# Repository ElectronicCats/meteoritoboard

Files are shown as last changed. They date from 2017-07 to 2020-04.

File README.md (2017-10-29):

# Meteorito Board

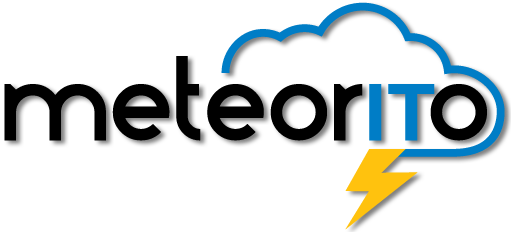
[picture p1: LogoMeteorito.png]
meteorito2


Kit de estación meteorologica para "Curso de estación y fenómenos meteorológicos" que funciona con La Red Meteorológica Ambiental([RedMet](http://redmet.org/)) promueve la difusión y concientización del cambio climático global. 

Manual, guía de arranque, curso completo y más información en [Pagina Oficial](http://meteorito.mx/index.html)

Electronic Cats invests time and resources providing this open source design, please support Electronic Cats and open-source hardware by purchasing products from Electronic Cats!

Designed by Electronic Cats.

Firmware released under an GNU AGPL v3.0 license. See the LICENSE file for more information.

Hardware released under an CERN Open Hardware Licence v1.2. See the LICENSE_HARDWARE file for more information.

Electronic Cats is a registered trademark, please do not use if you sell these PCBs.

22 July 2017

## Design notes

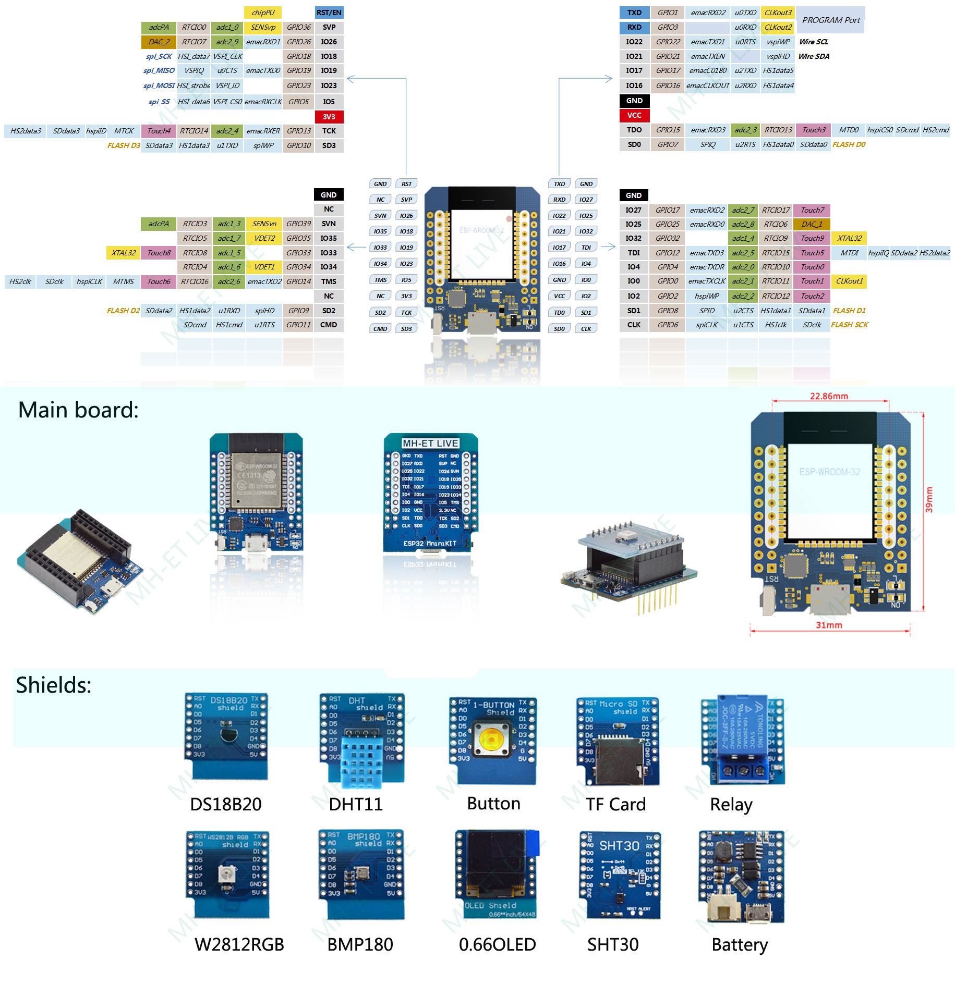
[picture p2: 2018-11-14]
MH-ET_LIVE_MINI_D1_ESP32.jpg

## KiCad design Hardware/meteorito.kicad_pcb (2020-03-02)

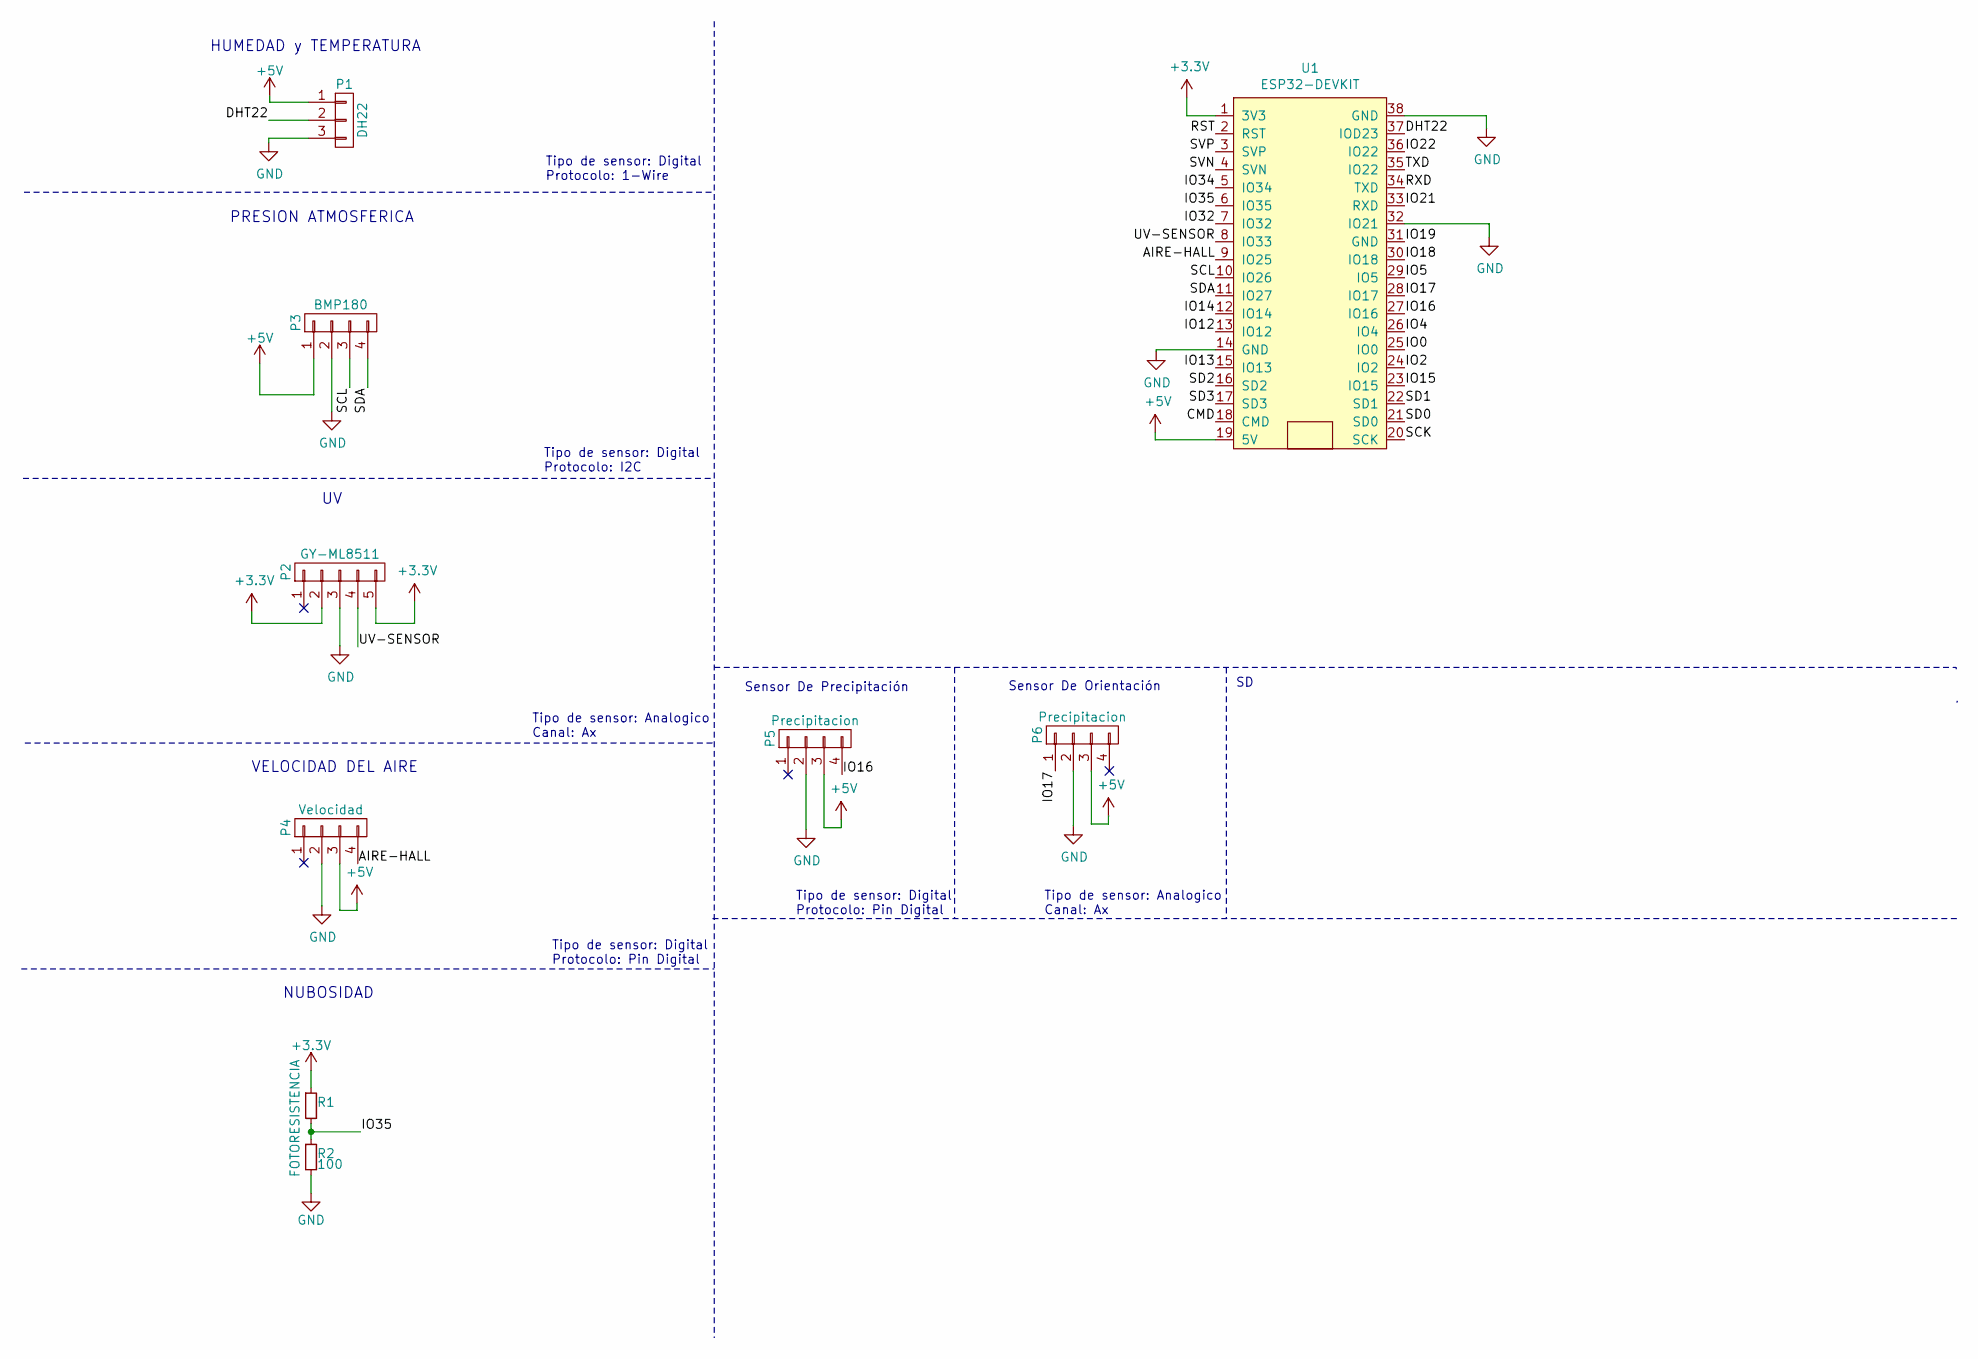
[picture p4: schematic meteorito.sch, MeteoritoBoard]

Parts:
P1: DH22; PinHeader_1x03_P2.54mm_Vertical
P2: GY-ML8511; PinHeader_1x05_P2.54mm_Vertical
P3: BMP180; PinHeader_1x04_P2.54mm_Vertical
P4: Velocidad; PinHeader_1x04_P2.54mm_Vertical
P5, P6: Precipitacion; PinHeader_1x04_P2.54mm_Vertical
R1: FOTORESISTENCIA; R_Axial_DIN0204_L3.6mm_D1.6mm_P2.54mm_Vertical
R2: 100; R_Axial_DIN0204_L3.6mm_D1.6mm_P7.62mm_Horizontal
U1: ESP32-DEVKIT

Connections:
+3V3: P2.2, P2.5, R1.1, U1.1 (3V3)
+5V: P1.1, P3.1, P4.3, P5.3, P6.3, U1.19 (5V)
/AIRE-HALL: P4.4, U1.9 (IO25)
/CMD: U1.18 (CMD)
/DHT22: P1.2, U1.37 (IOD23)
/IO0: U1.25 (IO0)
/IO2: U1.24 (IO2)
/IO4: U1.26 (IO4)
/IO5: U1.29 (IO5)
/IO12: U1.13 (IO12)
/IO13: U1.15 (IO13)
/IO14: U1.12 (IO14)
/IO15: U1.23 (IO15)
/IO16: P5.4, U1.27 (IO16)
/IO17: P6.1, U1.28 (IO17)
/IO18: U1.30 (IO18)
/IO19: U1.31 (GND)
/IO21: U1.33 (RXD)
/IO22: U1.36 (IO22)
/IO32: U1.7 (IO32)
/IO34: U1.5 (IO34)
/IO35: R1.2, R2.1, U1.6 (IO35)
/RST: U1.2 (RST)
/RXD: U1.34 (TXD)
/SCK: U1.20 (SCK)
/SCL: P3.3, U1.10 (IO26)
/SD0: U1.21 (SD0)
/SD1: U1.22 (SD1)
/SD2: U1.16 (SD2)
/SD3: U1.17 (SD3)
/SDA: P3.4, U1.11 (IO27)
/SVN: U1.4 (SVN)
/SVP: U1.3 (SVP)
/TXD: U1.35 (IO22)
/UV-SENSOR: P2.4, U1.8 (IO33)
GND: P1.3, P2.3, P3.2, P4.2, P5.2, P6.2, R2.2, U1.14 (GND), U1.32 (IO21), U1.38 (GND)

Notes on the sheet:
PRESION ATMOSFERICA
HUMEDAD y TEMPERATURA
VELOCIDAD DEL AIRE
NUBOSIDAD
Sensor De Precipitación
Sensor De Orientación
Tipo de sensor: Digital Protocolo: I2C
Tipo de sensor: Digital Protocolo: 1-Wire
Tipo de sensor: Analogico Canal: Ax
Tipo de sensor: Digital Protocolo: Pin Digital

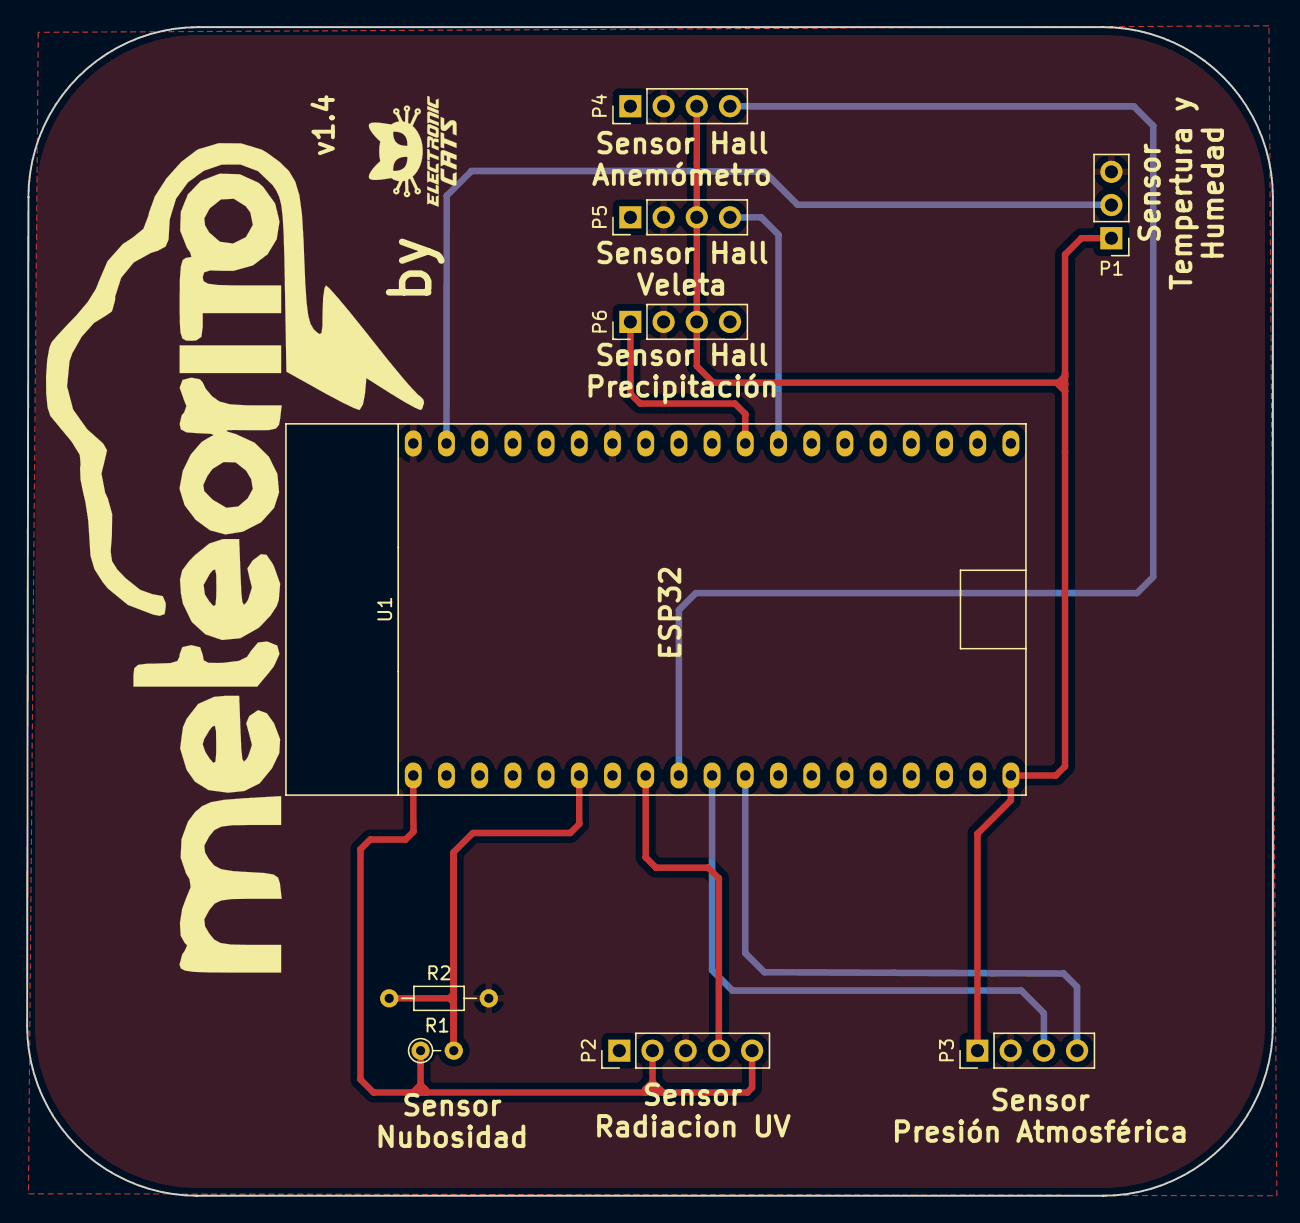
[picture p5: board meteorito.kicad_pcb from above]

Board: 2 copper layers, 95.3 x 89.4 mm, 10 parts (1 on the bottom side), 11 nets.

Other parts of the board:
svg2mod: electronic; titule_electronic_med

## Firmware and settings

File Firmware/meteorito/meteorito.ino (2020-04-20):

  /*******************************************************
Meteorito.ino
Ejemplo de Estacion Meteorologica con ESP32 
para redmet.org y Meteorito

Andres Sabas @ The Inventor's House
Brando Are @ Electronic Cats
Ricardo Villegas @ Electronic Cats


Fecha Original de Creación: 28 de Octubre del 2017
Ultima Actualizacion: 17 Abril 2020

Este ejemplo demuestra la conexion y envio de datos 
con un modulo ESP32 a la plataforma 
http://redmet.org

    Entorno de Desarrollo Especifico:  
  IDE: Arduino 1.8.4
  Plataforma de Hardware:
    - ESP32 WEMOS D1 Mini
    - DHT22
    - VEML6070
    - Fotoresistencia
    - BMP180
  o Tarjeta de desarrollo Meteorito   por Electronic Cats

Este código es beerware; si me ves 
(o cualquier otro miembro de Electronic Cats) 
por tu localidad, y ha encontrado útil nuestro código,
¡por favor cómprenos una ronda!

Distribuido tal cual; no se otorga ninguna garantía. 
Bajo Licencia MIT
************************************************************/
//Incluir la biblioteca WiFi
#include <WiFi.h>
#include "configuracion.h"
//Incluir la biblioteca BLE
 #include <BLEDevice.h>
#include <BLEUtils.h>
#include <BLEServer.h>
#include <BLE2902.h>
//Incluir la biblioteca Sensores
#include "DHT.h"
#include <Wire.h>
#include <Adafruit_Sensor.h>
#include <SFE_BMP180.h>

#define DEBUG
//#define DEBUG2

//TaskHandle_t Task1;
#define ALTITUDE 1888.0
SFE_BMP180 pressure;

sensors_event_t event;

#define DHTPIN 23  
#define DHTTYPE DHT22
float temperature;
float temperatura;
float humedad;
float presion2;
   
/*Variables Anemometro*/
const int pinAnemometro = 25;
unsigned long tiempoAntes;
unsigned long  tiempo=0;
unsigned long sumaTiempo=0;
byte contador=0;
bool bandera=0;
float velocidad = 0;

/*Variables uv*/
const byte pinRayosUV = 33;         //pin Analogico

/*Variables Nubosidad*/
const byte pinNubosidad = 35;

/*Variables Direccion de Viento*/
int sumaVeleta=0, i=0;      
const byte pinDireccion = 17;       //pin Analógico 
int direccion = 0;
const int tiempoEnvio=30;

//variables manejo de proceso precipitacion
float precipitacion = 0;
const byte pinPluviometro = 16;  //pin digital
unsigned long tiempoAntesDos;
unsigned long  tiempoDos=0;
unsigned long sumaTiempoDos=0;
byte contadorDos=0;
const int capacidadTotal=10;   //capacidad combinada de ambos lados en mL


DHT dht(DHTPIN, DHTTYPE);

bool _BLEClientConnected = false;

#define MeteoritoService BLEUUID((uint16_t)0x181A)
#define MeteoritoService2 BLEUUID((uint16_t)0x181B)

BLECharacteristic TemperaturaCharacteristics(BLEUUID((uint16_t)0x2A6E), BLECharacteristic::PROPERTY_READ );
BLECharacteristic HumedadCharacteristics(BLEUUID((uint16_t)0x2A6F), BLECharacteristic::PROPERTY_READ);
BLECharacteristic PresionCharacteristics(BLEUUID((uint16_t)0x2A6D), BLECharacteristic::PROPERTY_READ);
BLECharacteristic UvCharacteristics(BLEUUID((uint16_t)0x2A76), BLECharacteristic::PROPERTY_READ);
BLECharacteristic NubosidadCharacteristics(BLEUUID((uint16_t)0x2A58), BLECharacteristic::PROPERTY_READ);
//
BLECharacteristic VelocidadVientoCharacteristics(BLEUUID((uint16_t) 0x2A72), BLECharacteristic::PROPERTY_READ);
BLECharacteristic PrecipitacionCharacteristics(BLEUUID((uint16_t) 0x2A78), BLECharacteristic::PROPERTY_READ);
BLECharacteristic DireccionVientoCharacteristics(BLEUUID((uint16_t)0x2A73), BLECharacteristic::PROPERTY_READ);
//BLECharacteristic AltitudCharacteristics(BLEUUID((uint16_t) 0x2A6C), BLECharacteristic::PROPERTY_READ);

BLEDescriptor VelocidadVientoDescriptor(BLEUUID((uint16_t)0x290C));
BLEDescriptor PrecipitacionDescriptor(BLEUUID((uint16_t)0x290C));
BLEDescriptor TemperaturaDescriptor(BLEUUID((uint16_t)0x290C));
BLEDescriptor HumedadDescriptor(BLEUUID((uint16_t)0x290C));
BLEDescriptor PresionDescriptor(BLEUUID((uint16_t)0x290C));
BLEDescriptor UvDescriptor(BLEUUID((uint16_t)0x290C));
BLEDescriptor NubosidadDescriptor(BLEUUID((uint16_t)0x290C));
BLEDescriptor DireccionVientoDescriptor(BLEUUID((uint16_t)0x290C));
//BLEDescriptor AltitudDescriptor(BLEUUID((uint16_t)0x290C));

class MyServerCallbacks : public BLEServerCallbacks {
    void onConnect(BLEServer* pServer) {
      _BLEClientConnected = true;
    };

    void onDisconnect(BLEServer* pServer) {
      _BLEClientConnected = false;
    }
};

void InitBLE() {
  BLEDevice::init("Estación metereológica");
  // Create the BLE Server
  BLEServer *pServer = BLEDevice::createServer();
  pServer->setCallbacks(new MyServerCallbacks());

// Create the BLE Service
  BLEService *pMeteorito = pServer->createService(MeteoritoService);
//Caracteristica Temperatura
  pMeteorito->addCharacteristic(&TemperaturaCharacteristics);
  //TemperaturaDescriptor.setValue("Position 0 - 6");
  TemperaturaCharacteristics.addDescriptor(&TemperaturaDescriptor);
//Caracteristica Humedad
  pMeteorito->addCharacteristic(&HumedadCharacteristics);
  HumedadCharacteristics.addDescriptor(&HumedadDescriptor);
//Caracteristica Presión
 pMeteorito->addCharacteristic(&PresionCharacteristics);
  PresionCharacteristics.addDescriptor(&PresionDescriptor);
//Caracteristica Uv
 pMeteorito->addCharacteristic(&UvCharacteristics);
  UvCharacteristics.addDescriptor(&UvDescriptor);
//Caracteristica Nubosidad
 pMeteorito->addCharacteristic(&NubosidadCharacteristics);
 NubosidadCharacteristics.addDescriptor(&NubosidadDescriptor);



// Create the BLE Service
BLEService *pMeteorito2 = pServer->createService(MeteoritoService2);
//Caracteristica Dirección del viento
 pMeteorito2->addCharacteristic(&DireccionVientoCharacteristics);
 DireccionVientoCharacteristics.addDescriptor(&DireccionVientoDescriptor);
  //DireccionVientoDescriptor.setValue("Position 0 - 6");
//Caracteristica Velocidad del viento
 pMeteorito2->addCharacteristic(&VelocidadVientoCharacteristics);
 VelocidadVientoCharacteristics.addDescriptor(&VelocidadVientoDescriptor);
  //VelocidadVientoDescriptor.setValue("Position 0 - 6");
//Precipitacion
 pMeteorito2->addCharacteristic(&PrecipitacionCharacteristics);
  PrecipitacionCharacteristics.addDescriptor(&PrecipitacionDescriptor);
    //PrecipitacionDescriptor.setValue("Position 0 - 6");
//Altitud    
// pMeteorito2->addCharacteristic(&AltitudCharacteristics);
//  AltitudCharacteristics.addDescriptor(&AltitudDescriptor);*/

 pServer->getAdvertising()->addServiceUUID(MeteoritoService);
 pMeteorito->start();

 pServer->getAdvertising()->addServiceUUID(MeteoritoService2);
 pMeteorito2->start();

  // Start advertising
  pServer->getAdvertising()->start();
}

const char tipoNubosidad[5]={'C','M','N','P','D'};
  /* D - despejado
   * P - poco nuboso
   * N - nuboso
   * M - muy nuboso
   * C - cubierto
   * O - opcional
   */
//Formamos el header para enviar a la pagina
String httpHeader = "POST /api/device/metrics HTTP/1.1\r\n"
                    "Host: redmet.org\r\n" 
                    "Content-Type: application/json\r\n"
                    "Authorization: Basic "+ Token +"\r\n";

//Inicializar el WiFi cliente objeto
WiFiClient client;

/*Funcion para obtener direccion del viento */
int leerDireccion(int suma){
  suma=suma/tiempoEnvio;
  if(suma>=415 && suma< 440) return 0;
  if(suma>=440 && suma< 490) return 45;
  if(suma>=490 && suma< 510) return 90;
  if(suma>=540 && suma< 550) return 135;
  if(suma>=510 && suma< 525) return 18;
  if(suma>=525 && suma< 540) return 225;
  if(suma>=590 && suma< 615) return 270;
  if(suma>=615 && suma< 620) return 315;
}

// Funcion para obtener la luz ultravioleta
int leerUV(){
  int uv =map(analogRead(pinRayosUV),0,1350,0,15);
  return uv;
}

/*Funcion para obtener nubosidad*/
char nubosidad() {
  int lecturaSensor=analogRead(pinNubosidad);
  char nubosidad = tipoNubosidad[map(lecturaSensor, 0, 4095, 0, 4)];
  
  #ifdef DEBUG2
  Serial.print("Nubosidad: "); 
  Serial.println(nubosidad); 
  #endif

  return nubosidad;
}

/*Funcion para obtener presion y altura*/
float presion()
{
  char status;
  double T,P,P2,p0,a;
  status = pressure.startTemperature();
  if (status != 0)
  {
    // Wait for the measurement to complete:
    delay(status);
    // Retrieve the completed temperature measurement:
    // Note that the measurement is stored in the variable T.
    // Function returns 1 if successful, 0 if failure.
    status = pressure.getTemperature(T);
    if (status != 0)
    {
      status = pressure.startPressure(3);
      if (status != 0)
      {
        // Wait for the measurement to complete:
        delay(status);
        // Retrieve the completed pressure measurement:
        // Note that the measurement is stored in the variable P.
        // Note also that the function requires the previous temperature measurement (T).
        // (If temperature is stable, you can do one temperature measurement for a number of pressure measurements.)
        // Function returns 1 if successful, 0 if failure.
        status = pressure.getPressure(P,T);
        if (status != 0)
        {
          P2=P*0.1;
        }
        else Serial.println("error retrieving pressure measurement\n");
      }
      else Serial.println("error starting pressure measurement\n");
    }
    else Serial.println("error retrieving temperature measurement\n");
  }
  else Serial.println("error starting temperature measurement\n");
  
  return P2;
}

/*
 *Función de envio de datos via WiFi
 */
static void envioDatosWiFi() {
  if (client.connect(Servidor, 80) <= 0)
  {
    Serial.println(F("Fallo conexion a servidor."));
    return;
  }
  Serial.println(F("Connected."));

  //Asignar parametros a enviar:
  /*clouds, humidity, pressure, rain, temp, uv, windDirection, windSpeed*/
  String clouds, humidity, pressure, rain, temp, indiceUV, windDirection, windSpeed;
  
  clouds = String(nubosidad());
  humidity = String(humedad);
  pressure = String(presion());
  rain = String(precipitacion);
  temp = String(temperatura);
  indiceUV = String(leerUV());
  windDirection = String(direccion);
  windSpeed = String(velocidad);

// Cargamos una cadena con los datos
  
  /*
  * El formato es "{\"data\":{\"metrica\":valor}}"
  */
  
  //Ejemplo con un solo valor constante
  //String dato="{\"data\":{\"temp\":15}}";

  //Ejemplo con todos los valores posibles constantes
  //String dato="{\"data\":{\"clouds\":\"D\",\"humidity\":95,\"pressure\":145,\"rain\":245,\"temp\":15,\"uv\":13,\"windDirection\":9,\"windSpeed\":340}}";
  
  //Lectura de todos los valores posibles
  String dato="{\"data\":{\"clouds\":\""+clouds+"\",\"humidity\":\""+humidity+"\",\"pressure\":\""+pressure+"\",\"rain\":\""+rain+"\",\"temp\":\""+temp+"\",\"uv\":\""+indiceUV+"\",\"windDirection\":\""+windDirection+"\",\"windSpeed\":\""+windSpeed+"\"}}";
  
  #ifdef DEBUG
  Serial.println(F("Enviando datos!"));
  Serial.println(dato);
  #endif
  
  client.print(httpHeader);
  client.print("Content-Length: "); 
  client.println(dato.length());
  client.println();
  client.println(dato);

  unsigned long timeout = millis();
    while (client.available() == 0) {
        if (millis() - timeout > 5000) {
            Serial.println(">>> Client Timeout !");
            client.stop();
            return;
        }
    }

    // Read all the lines of the reply from server and print them to Serial
    while(client.available()) {
        String line = client.readStringUntil('\r');
        Serial.print(line);
    }
}

/*
 *Función de envio de datos via BLE
 */
static void envioDatosBLE(){
  
  //Temperatura
    uint8_t tempData[2];
    uint16_t tempValue;
    tempValue = (uint16_t)(temperatura *100);
    tempData[0] = tempValue;
    tempData[1] = tempValue>>8;
    TemperaturaCharacteristics.setValue(tempData,2);
    TemperaturaCharacteristics.notify(); 

  //Humedad 
  uint8_t humData[2];
  uint16_t humValue;
  humValue = (uint16_t)(humedad*100);
  humData[0] = humValue;
  humData[1] = humValue>>8;
  HumedadCharacteristics.setValue(humData,2);
  HumedadCharacteristics.notify(); 

 //Uvs
  uint8_t uvData[2];
  uint16_t uvValue;
  uvValue = (uint16_t)(leerUV()*100);
  uvData[0] = uvValue;
  uvData[1] = uvValue>>8;
  UvCharacteristics.setValue(uvData,2);
  UvCharacteristics.notify(); 
  
  //Presión
  uint8_t prData[2];
  uint16_t prValue;
  prValue = (uint16_t)(presion()*100);
  prData[0] = prValue;
  prData[1] = prValue>>8;
  PresionCharacteristics.setValue(prData,2);
  PresionCharacteristics.notify(); 
  
  //Nubosidad
  char nubo [5];
  dtostrf(nubosidad(),1,2,nubo);
  NubosidadCharacteristics.setValue(nubo);
  NubosidadCharacteristics.notify();

  //Precipitación
  uint8_t raData[2];
  uint16_t raValue;
  raValue = (uint16_t)(precipitacion*100);
  raData[0] = raValue;
  raData[1] = raValue>>8;
  PrecipitacionCharacteristics.setValue(raData,2);
  PrecipitacionCharacteristics.notify(); 

  //Velocidad del viento
  uint8_t VvData[2];
  uint16_t VvValue;
  VvValue = (uint16_t)(velocidad*100);
  VvData[0] = VvValue;
  VvData[1] = VvValue>>8;
  VelocidadVientoCharacteristics.setValue(VvData,2);
  VelocidadVientoCharacteristics.notify();

    //Dirección del viento
  uint8_t DvData[2];
  uint16_t DvValue;
  DvValue = (uint16_t)(direccion*100);
  DvData[0] = DvValue;
  DvData[1] = DvValue>>8;
  DireccionVientoCharacteristics.setValue(DvData,2);
  DireccionVientoCharacteristics.notify();

}

void setup () {
  Serial.begin(9600);
  Wire.begin(27,26);
  
  // initialize digital pin LED_BUILTIN as an output.
  pinMode(2, OUTPUT);

  Serial.println("\nIniciando Estacion Meteorito");
  Serial.println("por Electronic Cats");
 
  dht.begin();

  // Initializar el sensor BMP180
  if (pressure.begin())
      Serial.println("BMP180 init success");
  else{
      // Oops, something went wrong, this is usually a connection problem,
      // see the comments at the top of this sketch for the proper connections.
      Serial.println("BMP180 init fail\n\n");
      while(1); // Pause forever.
    }

// Verificación del modulo WiFi y la conexión a internet

  WiFi.begin(ssid, password);
  int cont = 0;
  while(cont<=10){
   (WiFi.status() != WL_CONNECTED); 
    delay(500);
    Serial.print(".");
    cont++;
    Serial.print(cont);
     
    }
   
//Tu estas conectado ahora
  Serial.println("\nTu estas conectado a la red WiFi");
  
  printWifiStatus();

  InitBLE();

  //Iniciamos anemometro
  pinMode(pinAnemometro, INPUT);
  attachInterrupt(digitalPinToInterrupt(pinAnemometro), interrupcionViento,RISING );
  tiempoAntes=millis();

  //Iniciamos pluviometro
   pinMode(pinPluviometro, INPUT);
   attachInterrupt(digitalPinToInterrupt(pinPluviometro), interrupcionPrecipitacion,RISING );
   tiempoAntesDos=millis();
}

void loop () {
  temperatura = dht.readTemperature();
  humedad = dht.readHumidity();
  
  //presion();
  presion2=(presion());
  
  if(i<tiempoEnvio){
    sumaVeleta+=analogRead(pinDireccion);
    i++;
  }
  else{
     direccion=leerDireccion(sumaVeleta);
     sumaVeleta=0; 
     i=0; 
  }
 
  noInterrupts();
  delayMicroseconds(200);
  envioDatosWiFi();
  envioDatosBLE();
  interrupts();  
  delayMicroseconds(200); 
  
  #ifdef DEBUG
  //Mostrar variables
  Serial.print("\n temperatura: ");
  Serial.print(temperatura);
  Serial.println(" celsius");
  Serial.print(" humedad: ");
  Serial.print(humedad);
  Serial.println(" %");
  Serial.print("UV nivel luz: "); 
  Serial.println(leerUV());
  Serial.print("Velocidad del viento: "); 
  Serial.print(velocidad,10);
  Serial.println("  Km/h");
  Serial.print("dirección: ");
  Serial.print(direccion);
  Serial.println(" °");
  Serial.print("Precipitacion: ");
  Serial.print(precipitacion);
  Serial.println(" mm/s");
  Serial.print("Presión Atmosferica: ");
  Serial.print(presion2);
  Serial.println(" Kpa");
  Serial.print("Nubosidad: ");
  Serial.println(nubosidad());
  #endif


  digitalWrite(2, HIGH);
  delay(500);                       
  digitalWrite(2, LOW);   
  delay(500);
   digitalWrite(2, HIGH);
  delay(500);                       
  digitalWrite(2, LOW);   
  delay(500);

}

/*
 * Funcion que imprime status de WiFi, 
 * nombre de red, local IP e intensidad de señal
*/
void printWifiStatus()
{
  // imprime el SSID de la red a la que está conectado
  Serial.print("SSID: ");
  Serial.println(WiFi.SSID());

  // imprime la dirección IP de tu estacion WiFi
  IPAddress ip = WiFi.localIP();
  Serial.print("IP Address: ");
  Serial.println(ip);

  // imprime la intensidad de la señal recibida
  long rssi = WiFi.RSSI();
  Serial.print("Signal strength (RSSI):");
  Serial.print(rssi);
  Serial.println(" dBm");
}


void interrupcionViento() {
  noInterrupts();
  if( millis()>(50+tiempoAntes)){
    bandera=!bandera;
    if(bandera==0){
      tiempo=(millis()-tiempoAntes);
      tiempoAntes=millis();
      sumaTiempo=+tiempo; 
      if(contador<=19){
        contador++;
        #ifdef DEBUG2
        Serial.println(contador);
        #endif
      }
      else{
        contador=0;
        velocidad=(2*3.1416*0.05*3.6)/((sumaTiempo/1000.0)/20);
        #ifdef DEBUG2
        Serial.print(velocidad);
        Serial.println("  Km/h");
        #endif
        sumaTiempo=0;
      }
    }
  }
  interrupts();
}

//Interrupcion para precipitación
void interrupcionPrecipitacion() {
  noInterrupts();
  if( millis()>(50+tiempoAntesDos)){
      tiempoDos=(millis()-tiempoAntesDos);
      tiempoAntesDos=millis();
      sumaTiempoDos+=tiempoDos; 
      if(contadorDos<=19){
        contadorDos++;
      }else{
        precipitacion=contadorDos*(((capacidadTotal*10)/(42.84))/(sumaTiempoDos/1000.0));
        contadorDos=0;
        sumaTiempoDos=0;
      }
  }
  interrupts();
}

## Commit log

2017-07-22 Added schematic 0.1
    [meteorito.kicad_pcb, meteorito.sch]
2017-07-22 images board
2017-10-29 Añadido ejemplo de conexion a redmet
    Sin test con esp8266
2017-10-30 variable de servidor correcta
    [meteorito.ino]
2017-10-30 Corregido formato de envio
2017-10-30 Agregado archivo de configuracion
2017-11-03 Agregado wemos lib
    Añadido etiquetas de conexión
    [meteorito.sch]
2017-11-10 Agregada funcion de nubosidad
    Sensor Fotoresistencia
2017-11-16 Agregado sensor DHT22
2017-11-16 Agregado temperatura y humedad a variables de ret met
2017-11-16 Corregido error de nubosidad
    [meteorito.ino]
2017-11-16 Actualizado impresion de variables
2017-11-28 Añadido sensor de UV por I2C VEML6070
2017-11-28 Agregado sensor de presion BMP180
    Presion, Altura y temperatura
2017-11-28 Cambiado mensaje de inicio
2017-11-28 Traduccion de varios textos a español
2017-11-28 Configuracion con ESP32
2017-12-20 Traducido mas textos de funciones
2017-12-21 Añadida funcion de recepcion de datos
2017-12-21 Cambiados pines de DHT22 y anerometro
    Usado pin 4 en OLED y pin 3 no disponible
2017-12-22 Agregado rango de presion y rayos UV
2018-06-25 Pin DHT22 change
2018-06-25 Cambio de pines y fix nubosidad
    [meteorito.ino]
2018-07-03 Update conectores
    [meteorito.sch]
2018-07-17 Variable para obtener temperatura de DHT22
2018-07-17 Alta de caracteristicas y servicios
2018-07-17 Función para inicializar BLE
2018-07-17 Envio de datos BLE
2018-07-20 Cambio de propiedad de la caracteristica
2018-07-20 end if de la variable que selecciona la comunicación, WiFi o BLE
2018-07-20 end if de la variable que selecciona el método de comunicación
2018-07-20 Variable de control para método de envio
2018-07-20 Cambiando el método de envio de datos en BLE
2018-07-20 Variable de control método de envio
2018-07-24 Actualizacion de informacion
2018-09-14 Se agregaron dos sensores de efecto Hall
    [meteorito-2018-09-14-16-52-21.sch, meteorito.sch]
2018-09-27 Velocidad del viento trabjando
2018-10-02 Cambios
    Se cambiaron errores que tenían algunos sensores y se asignaron etiquetas a los pines
    [meteorito.sch]
2018-10-10 FootPrints
    Se asignaron las FootPrints a los pines
    [meteorito.sch]
2018-10-10 Corregir cambios
    [meteorito.sch]
2018-10-26 Definicion de PCB
    [meteorito.kicad_pcb]
2018-10-30 Medidas iniciales
    [meteorito.kicad_pcb]
2018-10-31 add zones ground
    [meteorito.kicad_pcb]
2018-11-01 PCB Terminada
    [meteorito.kicad_pcb]
2018-11-13 Corrección
    Se colocaron la tierra y el VCC y se volvio a rootear lo faltante
    [meteorito.kicad_pcb, meteorito.sch]
2018-11-13 Nuevo Rooteo
    [meteorito.kicad_pcb]
2018-11-13 Remove NC pins
    [meteorito.kicad_pcb, meteorito.sch]
2018-11-13 Add hole M3
    [meteorito.kicad_pcb]
2018-11-14 Screw Hole
    [meteorito.kicad_pcb]
2018-11-14 Add image of ESP32
2018-11-14 Add led blink for send data
2018-11-14 Remove ref hole
    [meteorito.kicad_pcb]
2018-11-27 update pin UV
2018-11-27 update pin viento
2018-11-27 update precipitacion pin
2019-03-22 New ESP32 image
2019-03-22 Add error print
2019-03-27 Changes in ESP32 orientation
    [_saved_meteorito.sch]
2019-03-28 Sensor Labels added
    [meteorito.kicad_pcb]
2019-03-29 remove backups
    [_saved_meteorito.sch, meteorito-2018-09-14-16-52-21.sch]
2019-08-16 Interrupt anemometro work
2019-08-16 Fix air velocity
2020-02-14 Change in track
    [meteorito.kicad_pcb]
2020-02-14 fix pines
    [meteorito.kicad_pcb]
2020-02-28 Add library update components and layout
    [meteorito.kicad_pcb]
2020-03-02 Add labels pins
    [meteorito.kicad_pcb]
2020-04-20 Rename path
    [meteorito.kicad_pcb, meteorito.sch]
